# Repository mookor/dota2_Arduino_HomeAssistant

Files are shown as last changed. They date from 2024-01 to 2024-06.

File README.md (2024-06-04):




# dota2Arduino_HomeAssistan
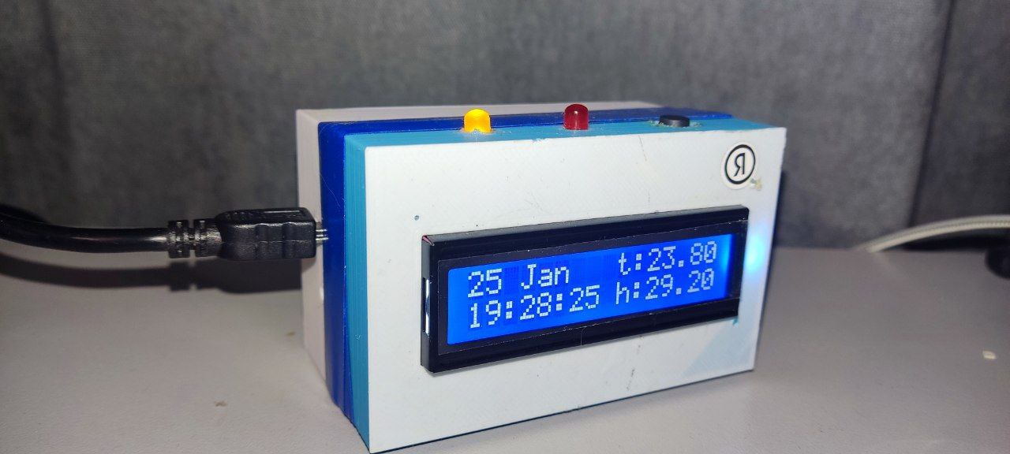
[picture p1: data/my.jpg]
\
A set of programs in C/Python that allows easy monitoring of respawn timings for Roshan/Lotuses/Wisdom Runes.
+ The installation itself serves as a clock with the current date, also displaying the current room humidity and temperature on the screen.
+ Temperature and humidity readings can be tracked through a Telegram bot, with the ability to create graphs for different time intervals and view current readings.
  
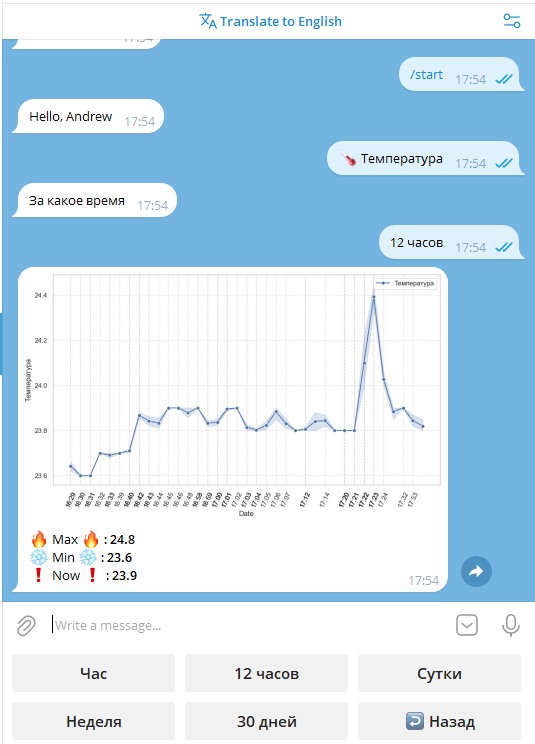
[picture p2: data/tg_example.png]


*charts are not supported right now, refactoring of the bot is required. There are implemented graphs from commit:* `68ac399d1c689f7ca0e62529d537f7c81e8da1c6`

## Description of Operation and System Preparation

### Installation
Simply run `pip install -e .` and all necessary dependencies will be installed.
### Arduino
In essence, you can assemble a separate device based on Arduino Nano to track timings, but pressing the device button during the game is not very convenient.

Assembly is done according to the following scheme.
The resistors on the diodes have a nominal value of ~500 Ohms, and the pull-up for the button is 10k Ohms.
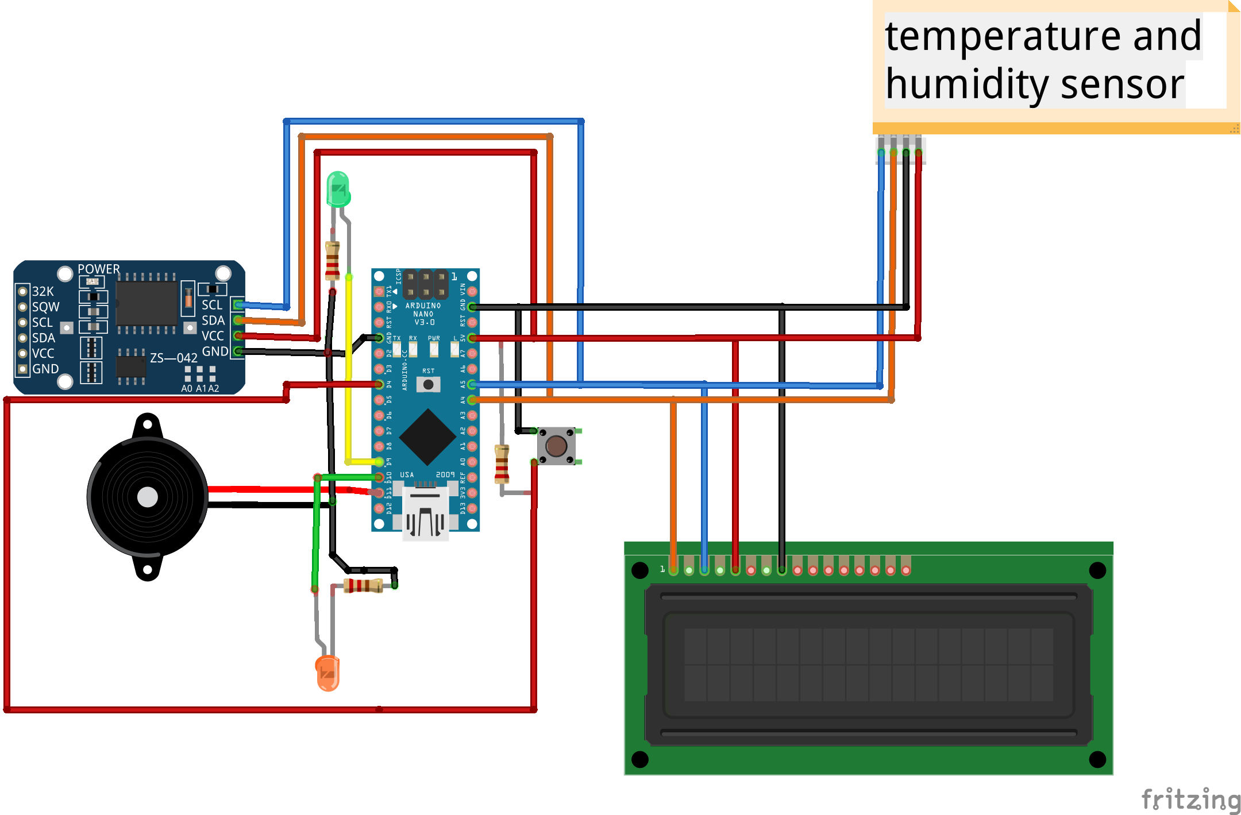
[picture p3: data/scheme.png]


### Arduino Control
- A double click on the start button initiates the game timer, displaying a three-minute countdown on the screen, showing Lotus timings. Also, 15 seconds before Lotus spawns, the LED starts blinking, and if sound is enabled, the buzzer plays a melody when there are 10 seconds left on the timer.
- A single click on the button signals that Roshan has died, initiating two timers: for 11 and 8 minutes respectively. The rest is similar to the first point.
- Holding the button will toggle the flag responsible for sound playback. The lit LED indicates whether the sound is on or off.

### PC Control
To control from a PC, the board must be powered via your computer's USB !
You can run it as a regular Python script with `main.py` or create an exe file for ease of use.

To create an exe file, simply run `pyinstaller --onefile --noconsole .\main.py`\
I do not guarantee the functionality of this method; it has not been tested.\
In the dist directory, you'll find the executable file that can be easily launched with a double click.

- Pressing F6 starts the game and Lotus timers.
- Pressing F7 notifies Arduino that Roshan has died.
- Pressing F8 toggles the flag responsible for sound playback (sound plays 15 seconds before any of the timings)\
  \
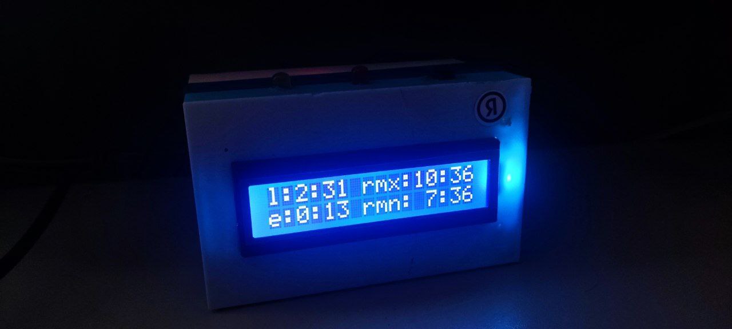
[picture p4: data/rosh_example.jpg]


### Automatic Control

During script execution, certain areas of the screen are scanned. Therefore, the game start flag may switch when the in-game clock reaches 00:00\
Similarly, there is a check for whether Roshan is alive or not; the flag switches automatically upon Roshan's death \
When the game ends, press F6/two clicks on the Arduino button; there is no automatic detection of the end of the game 

#### Running on Windows

For Windows users, simply replace the paths in the `run.bat` file and create a shortcut in the startup/desktop

## Additional Information

In the data folder, there is an icon for the application, and a model of the case for printing.

## Project scheme
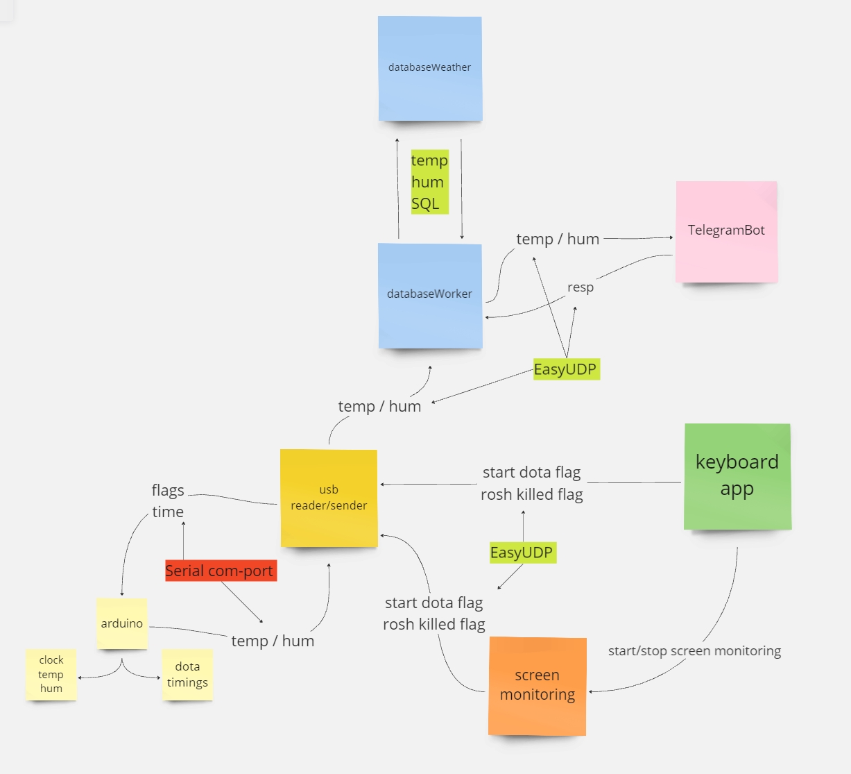
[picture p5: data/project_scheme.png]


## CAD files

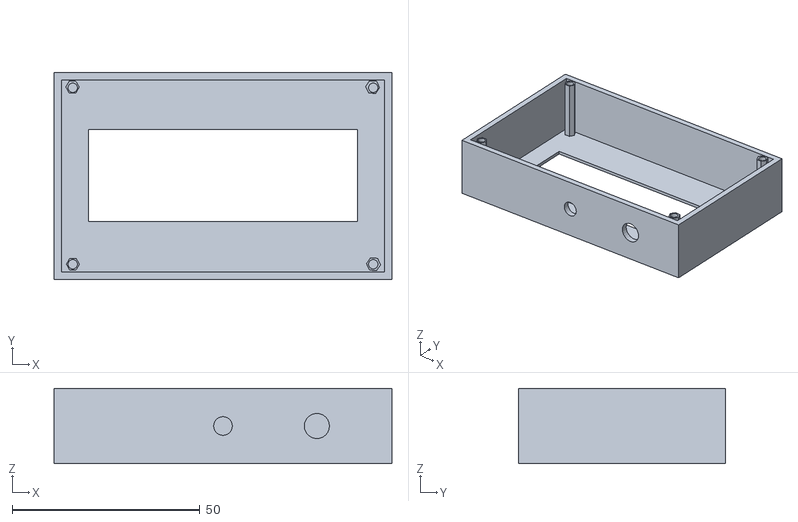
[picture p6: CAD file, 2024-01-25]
data/KORPUS2.stl
90.0 x 55.0 x 20.0

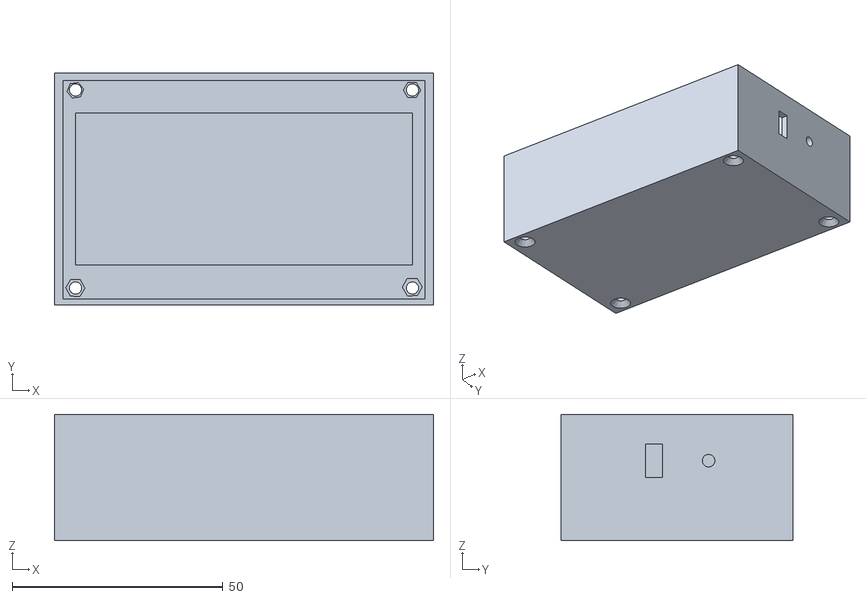
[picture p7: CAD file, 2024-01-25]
data/KORPUS1.stl
90.0 x 55.0 x 30.0

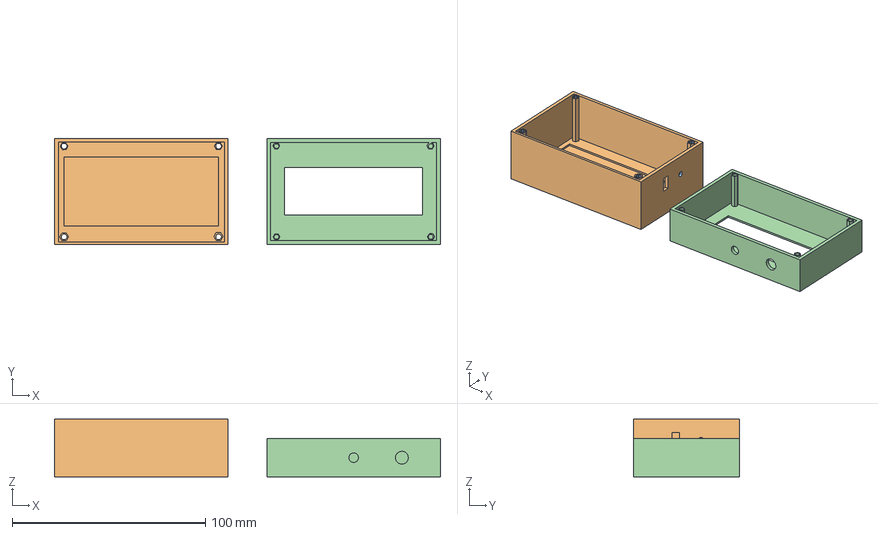
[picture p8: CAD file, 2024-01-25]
data/кад.FCStd
200.0 x 55.0 x 30.0 mm
Body001 (Meshed)
Body (Meshed)

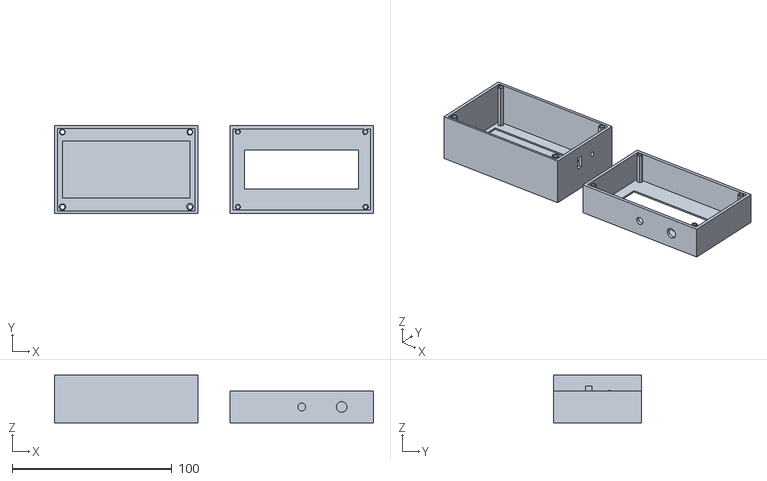
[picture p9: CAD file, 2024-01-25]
data/KORPUS3.stl
200.0 x 55.0 x 30.0

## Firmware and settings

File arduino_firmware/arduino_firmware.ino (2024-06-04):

#include "lcd.h"
#include "timer.h"
#include "wether.h"
#include "GyverButton.h"

GButton butt1(4);
uint32_t start_game_unix = 0;
uint32_t kill_rosh_unix = 0;
uint32_t weather_millis;
uint32_t cycle_millis;

time to_rosh;
time to_exp;
time to_lotus;

float t = 0;
float h = 0;

bool rosh_died = false;
bool start = false;
bool songing = false;
bool led_up = true;
bool lotus = false;
bool alarm_flag = false;

const char* months[] =
 {"Jan", "Feb", "Mar", "Apr", "May", "Jun", "Jul", "Aug", "Sep", "Oct", "Nov", "Dec"};

void setup()
{
  Serial.begin(9600);

  butt1.setDebounce(40);        // настройка антидребезга (по умолчанию 80 мс)
  butt1.setTimeout(1000);        // настройка таймаута на удержание (по умолчанию 500 мс)
  butt1.setClickTimeout(600); 
  butt1.setType(HIGH_PULL);
  butt1.setDirection(NORM_OPEN);
  
  weather_millis = millis();
  cycle_millis = millis();
  init_sensor();
  init_lcd();
  
  pinMode(10, OUTPUT);
  pinMode(9, OUTPUT);
  to_rosh.minutes = 1;
  to_rosh.seconds = 1;

  // rtc_set_time();
}

void alarm()
{
  int freq = random(800,1601);
  tone(11, freq, 400);
}
void buttons(String datas)
{
    char signal = datas[0];
    butt1.tick();  // обязательная функция отработки. Должна постоянно опрашиваться
    if (butt1.isDouble() || signal == 'g')
    {
        start_game_unix = get_unix();
        start = !start;
        lotus = !lotus;
        clear_lcd();
    }
    if (butt1.isSingle() || signal == 'r')
    {
        kill_rosh_unix = get_unix();
        start_game_unix = get_unix();
        start = true;
        lotus = true;
        rosh_died = true;
        clear_lcd();
    }
    if (butt1.isHolded() || signal == 'b')
    {
        songing = !songing;
    }
    if (signal == 'a')
    {
      alarm_flag = true;
    }
    if (butt1.isTriple())
    {
      alarm_flag = false;
    }
}

void beep(time timing)
{
  if(songing)
    if (timing.minutes == 0 && 13 <= timing.seconds && timing.seconds <= 15)
      tone(11, 784, 1000);
  
}

void led_up_down()
{
  if(to_lotus.minutes == 0 && to_lotus.seconds <= 15 || to_exp.minutes == 0 && to_exp.seconds <= 15 || to_rosh.minutes == 0 && to_rosh.seconds <= 15)
  {
    digitalWrite(10, HIGH);
  }
  else
  {
    digitalWrite(10, LOW);
  }
}
void draw_lotus(time timing)
{
  print_lcd(" ", 5, 0);
  print_lcd((String) "l:" + timing.minutes + ":" + timing.seconds, 0, 0);
  beep(timing);
 
}

void draw_exp(time timing)
{
  print_lcd(" ", 5, 1);
  print_lcd((String) "e:" + timing.minutes + ":" + timing.seconds, 0, 1);
  beep(timing);
 
}

void draw_rosh(time timing_max)
{
  uint32_t min_rosh = 8 * 60;
  time timing_min = get_seconds_to_moment(kill_rosh_unix, min_rosh);
  String space = timing_max.minutes <= 9 ? ": " : ":";
  print_lcd(" ", 15, 0);
  print_lcd((String) "rmx" + space + timing_max.minutes + ":" + timing_max.seconds, 7, 0);
  if (timing_max.minutes > 3 && timing_max.seconds > 0)
  {
    print_lcd(" ", 15, 1);
    print_lcd((String) "rmn: " + timing_min.minutes + ":" + timing_min.seconds, 7, 1);
  }
  else
  {
    print_lcd("         ", 7, 1);
  }
  if (timing_max.minutes == 0 && timing_max.seconds <= 1)
  {
    rosh_died = false;
    print_lcd("         ", 7, 0);
  }
  beep(timing_max);
}

void set_time_from_char_array(String readData)
{
  // second = third and fourth byte
  Serial.println(readData);
  if (readData[0] == 's')
  {
    char str[3];
    str[0] = readData[2];
    str[1] = readData[3];
    str[2] = '\0';
    int8_t seconds = atoi(str);
    // minute = fifth and sixth byte
    str[0] = readData[7];
    str[1] = readData[8];
    str[2] = '\0';
    int8_t minutes = atoi(str);
    // hour = seventh and eighth byte
    str[0] = readData[12];
    str[1] = readData[13];
    str[2] = '\0';
    int8_t hours = atoi(str);
    // date = nineth and tenth byte
    str[0] = readData[17];
    str[1] = readData[18];
    str[2] = '\0';
    int8_t date = atoi(str);
    // month = eleventh and twelfth byte
    str[0] = readData[24];
    str[1] = readData[25];
    str[2] = '\0';
    int8_t month = atoi(str);
    // year = thirteenth and fourteenth byte
    char str2[5];
    str2[0] = readData[29];
    str2[1] = readData[30];
    str2[2] = readData[31];
    str2[3] = readData[32];
    str2[4] = '\0';
    int16_t year = atoi(str2);
    rtc_set_time(seconds, minutes, hours, date, month, year);
  }
}
void loop()
{
  String datas = Serial.readStringUntil('\n');
  set_time_from_char_array(datas);
  delay(20);
  buttons(datas);
  
  songing ? digitalWrite(9, HIGH): digitalWrite(9, 0);

  delay(20);
  if (millis() - weather_millis > 1000)
  {
    wether_sensor_data data = get_wether();
    t = data.temperature;
    h = data.humidity;
    weather_millis = millis();
  }
  if (millis() - cycle_millis > 1000)
  {
    delay(20);
    if (start)
    {

        if (lotus)
        { 
          to_lotus = get_seconds_to_moment(start_game_unix, 3 * 60);
          draw_lotus(to_lotus);
          to_exp = get_seconds_to_moment(start_game_unix, 7 * 60);
          draw_exp(to_exp);
        }
        if (rosh_died)
        {
          to_rosh = get_seconds_to_moment(kill_rosh_unix, 11 * 60);
          draw_rosh(to_rosh);
        }
        led_up_down();
    }
    else
    {
        if (rosh_died || lotus)
        {
          clear_lcd();
          rosh_died  = lotus = false;
        }
        print_lcd(get_date(), 0, 0);
        print_lcd(months[get_month()-1], 3, 0);
        print_lcd((String) " t:" + t, 8, 0);

        print_lcd(get_time_string(), 0, 1);
        print_lcd((String) "h:" + h, 9, 1);
        
    }

    if (alarm_flag)
      alarm();

    cycle_millis = millis();
  }
}

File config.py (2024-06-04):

USB_DBWORKER_PORT = 62000
BOT_DBWORKER_PORT = 62001
DBWORKER_BOT_PORT = 62003
APPS_USB_PORT = 62002

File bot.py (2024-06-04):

from aiogram import Bot, Dispatcher, types
from aiogram.contrib.fsm_storage.memory import MemoryStorage
from aiogram.contrib.middlewares.logging import LoggingMiddleware
from aiogram.types import BotCommand
from aiogram.utils import executor
from dotenv import load_dotenv
from bot_states import States
import time
from easy_udp import UDPSender, UDPReceiver
from config import BOT_DBWORKER_PORT, DBWORKER_BOT_PORT
from datetime import datetime, timedelta
import os
import numpy as np

async def current_weather():
    sender.send("current")
    time.sleep(0.5)
    data = receiver.receive()
    temperature = data[1]
    humidity = data[2]
    return temperature, humidity

def get_time_delta(time_interval):
    time_dict = {"Час" : "hour", 
                 "12 часов" : "half_day", 
                 "Сутки" : "day", 
                 "Неделя" : "week", 
                 "30 дней" : "month"}
    
    hours_dict = {
                    "hour" : 1, 
                    "half_day" : 12, 
                    "day" : 24, 
                    "week" : 168, 
                    "month" : 720
                 }
    delta = datetime.now() - timedelta(hours=hours_dict[time_dict[time_interval]])
    return delta

async def setup_bot_commands(dp):
    bot_commands = [
        BotCommand(command="/start", description="Начать опрос"),
    ]
    await bot.set_my_commands(bot_commands)

def additional_keyboard():
    markup = types.ReplyKeyboardMarkup(resize_keyboard=True)
    btn1 = types.KeyboardButton("Час")
    btn2 = types.KeyboardButton("12 часов")
    btn3 = types.KeyboardButton("Сутки")
    btn4 = types.KeyboardButton("Неделя")
    btn5 = types.KeyboardButton("30 дней")
    btn6 = types.KeyboardButton("↩️ Назад")
    markup.add(btn1, btn2, btn3, btn4, btn5, btn6)
    return markup

def main_keyboard():
    markup = types.ReplyKeyboardMarkup(resize_keyboard=True)
    btn1 = types.KeyboardButton("💦 Влажность")
    btn2 = types.KeyboardButton("🌡️ Температура")
    btn3 = types.KeyboardButton("📊 Текущие показатели")
    
    markup.add(btn1, btn2, btn3)
    return markup

if load_dotenv():
    API_TOKEN = os.getenv("BOT_TOKEN")
else:
    os._exit(1)

bot = Bot(token=API_TOKEN)
dp = Dispatcher(bot, storage=MemoryStorage())
dp.middleware.setup(LoggingMiddleware())
sender = UDPSender(host="localhost", port=BOT_DBWORKER_PORT)
receiver = UDPReceiver(host="localhost", port=DBWORKER_BOT_PORT)



@dp.message_handler(commands=["start"], state="*")
async def start(message: types.Message):
    await message.answer("Choose what you want", reply_markup=main_keyboard())
    await States.choose.set()

@dp.message_handler(state=States.choose)
async def choose(message: types.Message, state: States.choose):
    if message.text == "💦 Влажность":
        await message.answer("Choose time interval:", reply_markup=additional_keyboard())
        await States.humidity.set()

    elif message.text == "🌡️ Температура":
        await message.answer("Choose time interval:", reply_markup=additional_keyboard())
        await States.temp.set()

    elif message.text == "📊 Текущие показатели":
        temperature, humidity = await current_weather()
        await message.answer(f"🔥 Температура: {temperature}°C\n💧Влажность: {humidity}%", reply_markup=main_keyboard())

@dp.message_handler(state=States.temp)
async def temperature(message: types.Message, state: States.temp):

    interval = get_time_delta(message.text)
    sender.send(np.array([str(interval), str(datetime.now())]))

    time.sleep(0.1)

    data = receiver.receive()
    
    if data is None:
        await message.answer("Нет данных")
    else:
        data = data.split('_')
        data = data[1::3]
        data = list(map(float, data))

        mean_data = sum(data) / len(data)

        await message.answer(f"🔥 Средняя температура за {message.text}: {mean_data:.2f}°C\n", reply_markup=main_keyboard())
    
    await States.choose.set()

@dp.message_handler(state=States.humidity)
async def humidity(message: types.Message, state: States.temp):

    interval = get_time_delta(message.text)
    sender.send(np.array([str(interval), str(datetime.now())]))

    time.sleep(0.1)

    data = receiver.receive()
    
    if data is None:
        await message.answer("Нет данных")
    else:
        data = data.split('_')
        data = data[2::3]
        data = list(map(float, data))

        mean_data = sum(data) / len(data)

        await message.answer(f"💧 Средняя влажность: за {message.text}: {mean_data:.2f}°C\n", reply_markup=main_keyboard())
    
    await States.choose.set()

if __name__ == "__main__":
    executor.start_polling(dp, skip_updates=True, on_startup=setup_bot_commands)

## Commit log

2024-01-25 arduino firmware
2024-01-25 instumetns for screen monitoring and arduino controll
2024-01-25 added some helpfull data
    [KORPUS1.stl, KORPUS2.stl, KORPUS3.stl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]
2024-01-25 add example of end device
2024-01-25 fix problem with exp timings
    [arduino_firmware.ino]
2024-01-25 поправил ситуацию, когда могли быть случаи без получения инфы по графикам
2024-01-25 убрал регион - можно вернуть для увеличения производительности
2024-01-25 Добавил кнопку, которой можно убивать запущенную программу
2024-05-22 update arduino code -> added set_time call
2024-05-22 fix problem with \n by readStringUntil
    [arduino_firmware.ino]
